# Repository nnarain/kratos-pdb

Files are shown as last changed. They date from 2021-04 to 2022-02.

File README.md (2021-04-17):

# Kratos PDB




A simple power distribution board for personal projects.

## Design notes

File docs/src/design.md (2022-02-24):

# Design Summary

Schematics can be found here: {{#find schematic}}.

To view the bill of materials and see the PCB layout click here: {{#find ibom}}

Voltage Regulators
------------------

This board has 2 cascading voltage regulators: 5V and 3.3V.

The main step down from the input voltage is done with a switch mode power supply and outputs 5V. This is done for power efficiency. From 5V a linear regulator is used to output 3.3V.

Interface
---------

The board implements the "Icarus" shield pinout, to be compatible with the [Icarus Controller](https://github.com/nnarain/icarus).

In addition, 4 pairs of PWR and GND pads are available at each corner of the board, to supply power to ESCs (if applicable).

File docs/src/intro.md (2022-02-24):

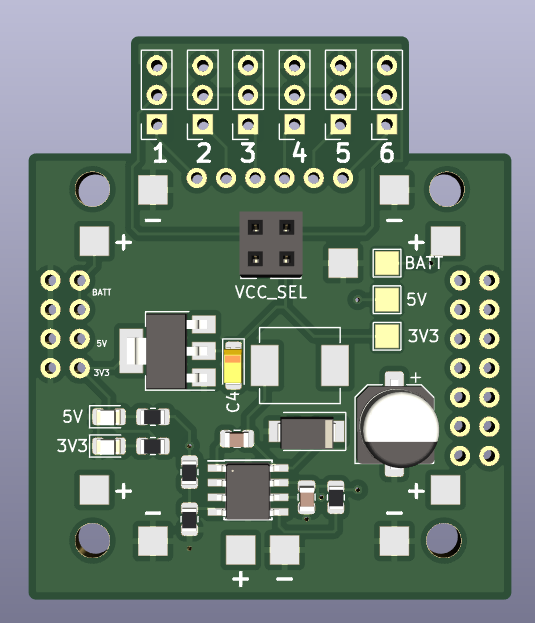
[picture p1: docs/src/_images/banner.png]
Image not found


This is a simple power distribution board for personal projects.

Features:

* 5V and 3.3V output
* Can support 2s to 6s LiPo batteries
* 30.5mm x 30.5mm mounting holes
* 6 servo headers
* Pads for ESCs

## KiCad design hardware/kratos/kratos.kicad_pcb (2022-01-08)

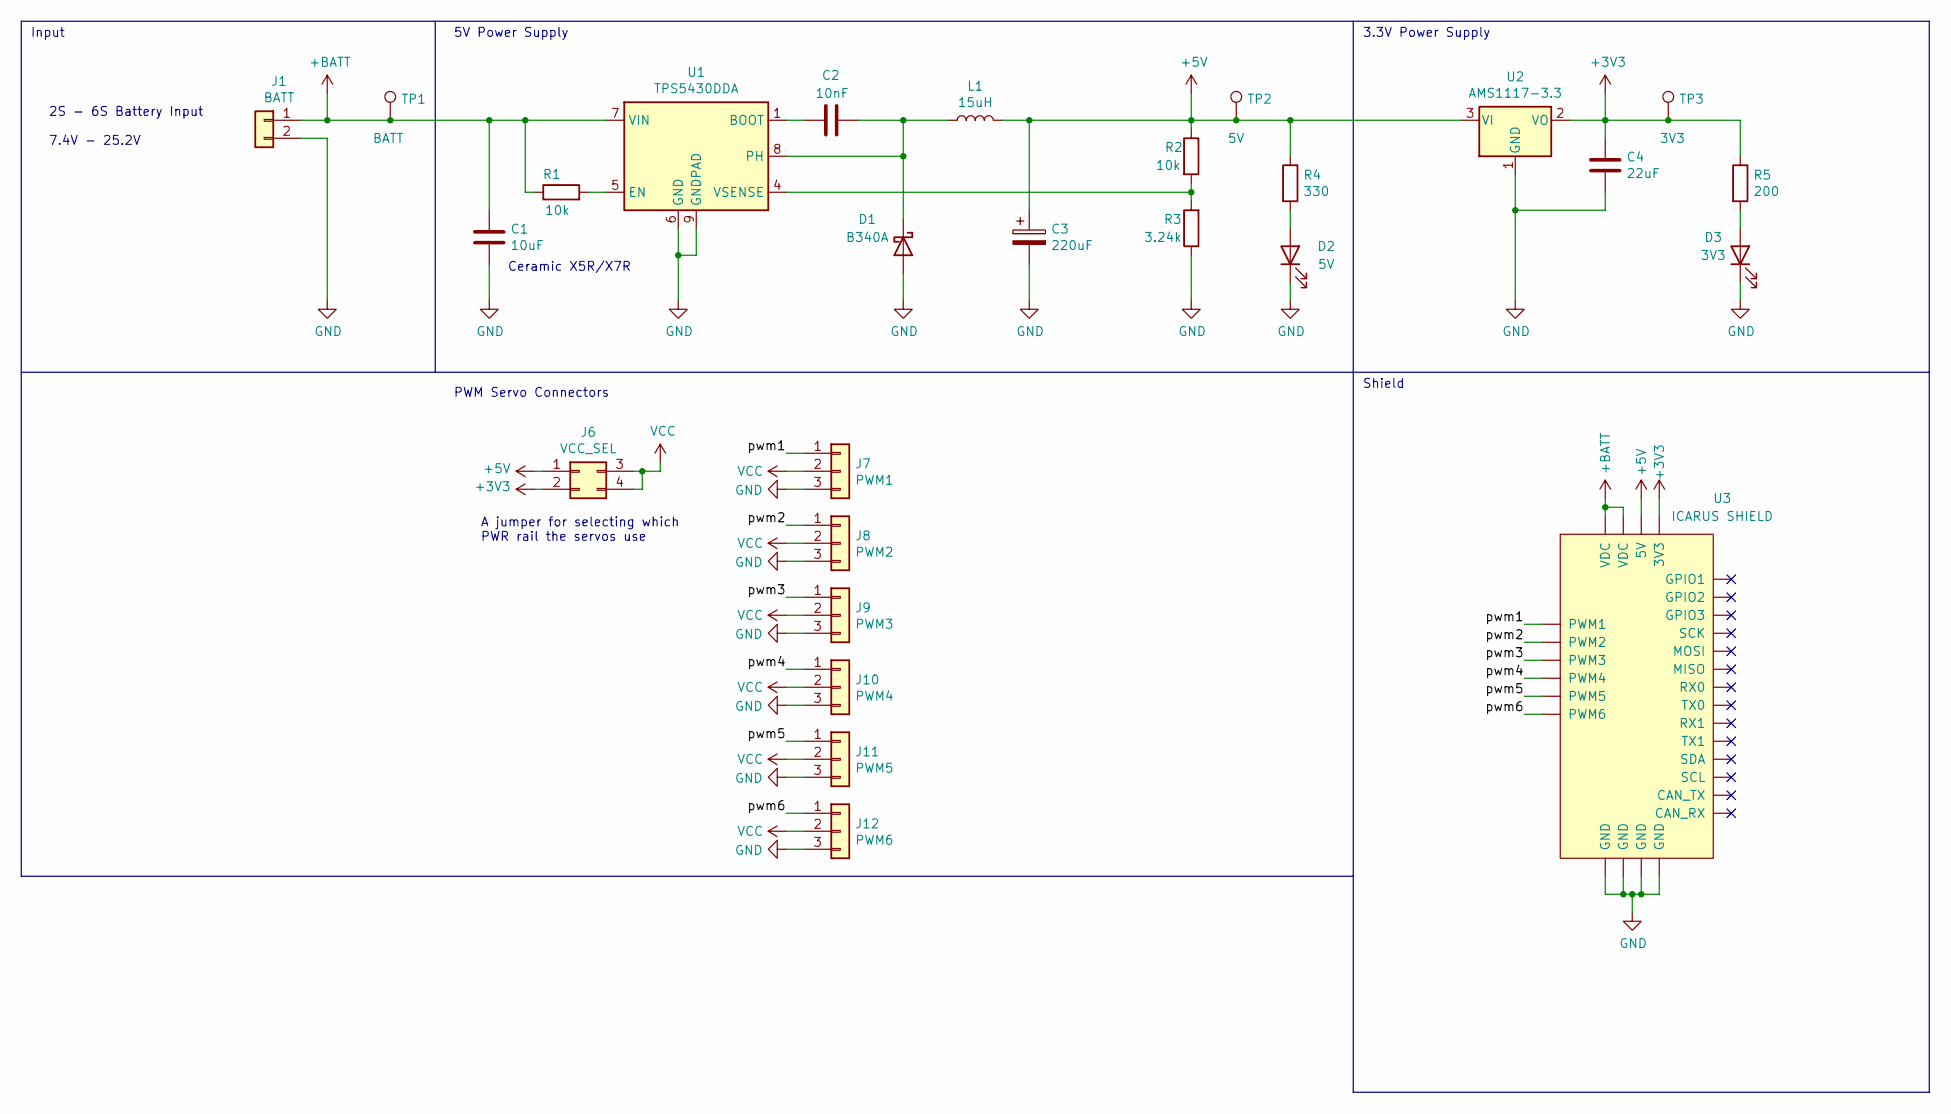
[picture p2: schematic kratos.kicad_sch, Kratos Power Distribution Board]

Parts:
C1: 10uF; C_0805_2012Metric; LCSC C440198
C2: 10nF; C_0805_2012Metric; LCSC C1710
C3: 220uF; CP_Elec_6.3x5.4; LCSC C3345
C4: 22uF; CP_EIA-3216-18_Kemet-A; LCSC C116575
D1: B340A; D_SMA; LCSC C64982
D2: 5V; LED_0805_2012Metric; LCSC C95814
D3: 3V3; LED_0805_2012Metric; LCSC C95814
J1: BATT; XT60
J6: VCC_SEL; PinSocket_2x02_P2.54mm_Vertical
J7: PWM1; PinSocket_1x03_P2.54mm_Vertical
J8: PWM2; PinSocket_1x03_P2.54mm_Vertical
J9: PWM3; PinSocket_1x03_P2.54mm_Vertical
J10: PWM4; PinSocket_1x03_P2.54mm_Vertical
J11: PWM5; PinSocket_1x03_P2.54mm_Vertical
J12: PWM6; PinSocket_1x03_P2.54mm_Vertical
L1: 15uH; MWSA0603S-150MT; LCSC C408452
R1, R2: 10k; R_0805_2012Metric; LCSC C17408
R3: 3.24k; R_0805_2012Metric; LCSC C64285
R4: 330; R_0805_2012Metric; LCSC C17630
R5: 200; R_0805_2012Metric; LCSC C17540
TP1: BATT; TestPoint_Pad_2.0x2.0mm
TP2: 5V; TestPoint_Pad_2.0x2.0mm
TP3: 3V3; TestPoint_Pad_2.0x2.0mm
U1: TPS5430DDA; TI_SO-PowerPAD-8_ThermalVias; LCSC C9864
U2: AMS1117-3.3; SOT-223-3_TabPin2; LCSC C6186
U3: ICARUS SHIELD; icarus-shield

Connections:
+3V3: C4.1, J6.2, R5.1, TP3.1, U2.2 (VO), U3.8 (3V3)
+5V: C3.1, J6.1, L1.2, R2.1, R4.1, TP2.1, U2.3 (VI), U3.6 (5V)
+BATT: C1.1, J1.1, R1.1, TP1.1, U1.7 (VIN), U3.2 (VDC), U3.4 (VDC)
/pwm1: J7.1, U3.9 (PWM1)
/pwm2: J8.1, U3.10 (PWM2)
/pwm3: J9.1, U3.11 (PWM3)
/pwm4: J10.1, U3.12 (PWM4)
/pwm5: J11.1, U3.13 (PWM5)
/pwm6: J12.1, U3.14 (PWM6)
GND: C1.2, C3.2, C4.2, D1.2 (A), D2.1 (K), D3.1 (K), J1.2, J7.3, J8.3, J9.3, J10.3, J11.3, J12.3, R3.1, U1.6 (GND), U1.9 (GNDPAD), U2.1 (GND), U3.1 (GND), U3.3 (GND), U3.5 (GND), U3.7 (GND)
unnamed: C2.1, U1.1 (BOOT)
unnamed: C2.2, D1.1 (K), L1.1, U1.8 (PH)
unnamed: D2.2 (A), R4.2
unnamed: D3.2 (A), R5.2
unnamed: R1.2, U1.5 (EN)
unnamed: R2.2, R3.2, U1.4 (VSENSE)
VCC: J6.3, J6.4, J7.2, J8.2, J9.2, J10.2, J11.2, J12.2

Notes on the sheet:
3.3V Power Supply
Shield
2S - 6S Battery Input 7.4V - 25.2V
A jumper for selecting which PWR rail the servos use
5V Power Supply
Ceramic X5R/X7R
Input
PWM Servo Connectors

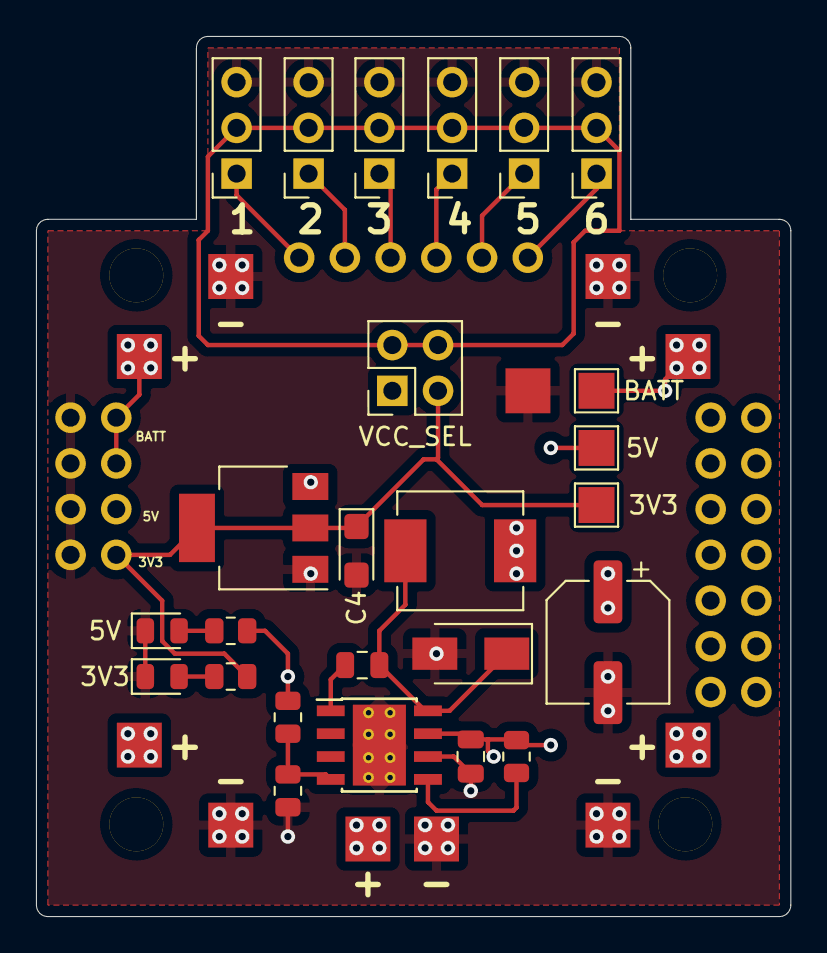
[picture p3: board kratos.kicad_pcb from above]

Board: 4 copper layers, 41.9 x 48.9 mm, 27 parts (0 on the bottom side), 17 nets.

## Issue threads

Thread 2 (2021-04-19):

Input connection

nnarain, 2021-04-19:
Probably remove the barrel jack and just expose pads to solder to. Save space on the board and enabled different input options.

Possible option for wired projects is to use a XT60 to barrel adapter.

Closed 2021-09-06.

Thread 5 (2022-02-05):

LiPo Charging

nnarain, 2022-02-05:
LiPo chargers seem pretty common in various dev board (though it may only be for single cells)

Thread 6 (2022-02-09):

Curious about assembly: done yourself?

gauteh, 2022-02-09:
Hi,

I was curious about how you do the assembly of the various SMT components. Do you do it yourself or do you get PCB manufacturer to do it? Do you have any recommendations?

Best regards, Gaute

nnarain, 2022-02-10:
I've been using JLCPCB for my recent projects and its been pretty good so far.

Basically you just pick from their parts library: https://jlcpcb.com/parts

And export a BOM with the LCSC part  number for each component.

gauteh, 2022-02-10:
Thanks a lot. I've been looking at JLCPCB too. Do you design in kicad or use their easyeda?

gauteh, 2022-02-11:
Thanks!

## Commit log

2021-03-08 Initial design schematic
    [breakout.sch, input.sch, kratos.kicad_pcb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]
2021-03-17 Update to linear regulators. Added PCB layout
    [breakout.sch, input.sch, kratos.kicad_pcb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]
2021-03-18 update text
    [kratos.kicad_pcb]
2021-03-19 Update digikey part numbers in schematics
    [input.sch, powersupply_12v.sch, powersupply_3v3.sch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]
2021-03-19 Update tantalum cap to polarized
    [powersupply_12v.sch, powersupply_5v.sch]
2021-04-17 Update part number
    [input.sch]
2021-09-06 Rev B
    [breakout.sch, input.sch, kratos.kicad_pcb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]
2021-12-06 Layer update
    [kratos.kicad_pcb]
2022-01-08 REV C
    [breakout.sch, input.sch, kratos.kicad_pcb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]
2022-01-26 Fix 10k resistor JLCPCB selection
    [kratos.kicad_sch]
2022-02-24 Kibot config. Updated book
    [kratos.kicad_sch]
